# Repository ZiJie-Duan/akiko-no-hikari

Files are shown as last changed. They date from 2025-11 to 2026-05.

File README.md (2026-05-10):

# Akiko-no-Hikari (晶子の光)
# Miniature Melbourne City Lighting Model

*Read this in other languages: [简体中文](README_CH.md), [Original Chinese Version](README_CH_Original.md)*

## Project Overview
This is a farewell gift for my friend to commemorate our life in Melbourne. It's a miniature Melbourne city model with added lighting effects that can simulate sunrise, sunset, and nighttime.

**Demo Video**: https://youtu.be/LcSbfyCi86A

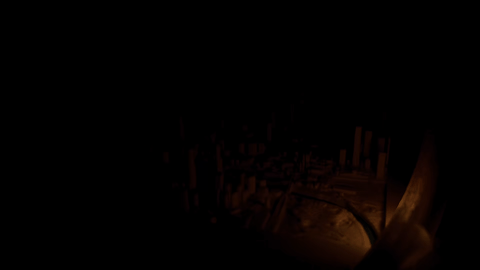
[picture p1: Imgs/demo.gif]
Project Demo


This project involves multiple steps including 3D printing, electronic soldering, and microcontroller programming. In the following text, I will explain how to build this project.

## Materials List
- **3D Printer** (I used Bambu Lab A1)
- **3D Printing Materials**:
  - PLA_Matte (for the frame)
  - PETG_Transparent (for the light-transmitting LED track)
  - Bambu Lab official materials
- **Electronic Components**:
  - Raspberry Pi Pico RP2040 (stamp pad version)
  - WS2812 LED strip (48 LEDs, high-density version with 144 LEDs/meter)
- **Tools**:
  - Electronic soldering tools (solder, soldering iron, wires, etc.)
  - Strong adhesive (for bonding PLA_Matte and PETG_Transparent materials)

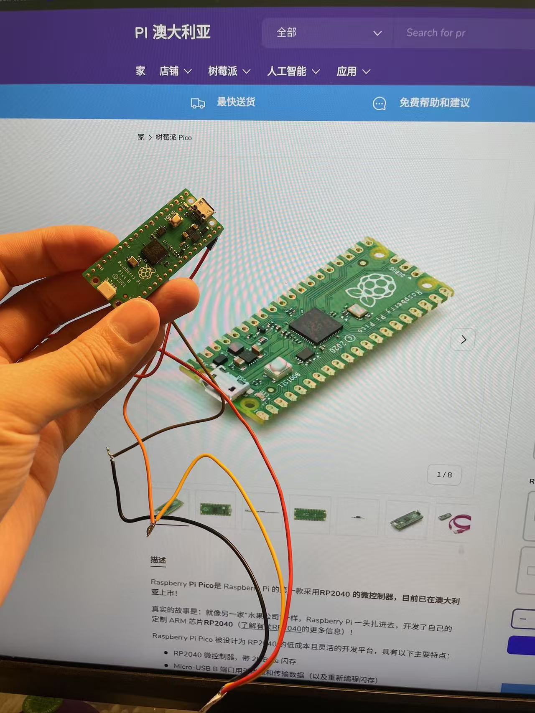
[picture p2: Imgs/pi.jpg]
Raspberry Pi Pico


## Construction Process

The construction is divided into three main steps:
1. 3D Printing
2. Assembly and Soldering
3. Programming

### 1. 3D Printing
In the `3D_models` folder of the project directory, there are three files:
- `akiko_no_hikari_project.f3d`: Complete model (can be edited with Fusion 360)
- `frame.stl`: Frame and various components (to be printed with PLA_Matte material)
- `solar_track.stl`: Light-transmitting LED track (to be printed with PETG_Transparent material)

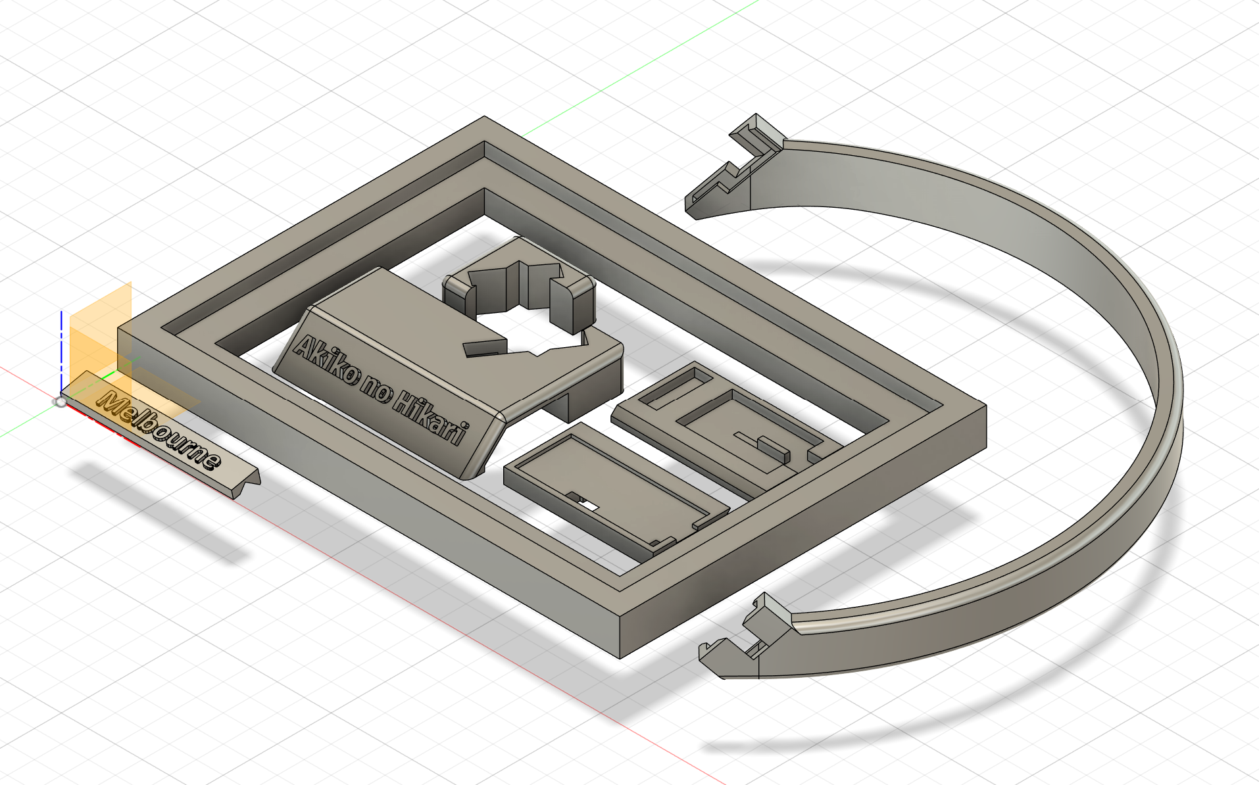
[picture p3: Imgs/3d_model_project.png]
3D Model


If you need to edit the model yourself, you can download akiko_no_hikari_project.f3d and open it with Fusion 360.

If you just want to print and assemble the model, you can directly download frame.stl and solar_track.stl for printing.

frame.stl should be printed with PLA Matte material, and solar_track.stl should be printed with PETG Transparent material.

**Printing Notes**:
- When printing `solar_track.stl`, adjust the support options:
  - Only use tree supports
  - Supports should only grow from the bottom up (no supports inside the model)
  - Pay attention to print speed and temperature control

### 2. Assembly and Soldering
1. **Connecting the Raspberry Pi Pico**:
   - Solder three wires to the stamp pads:
     - 5V power wire
     - GND ground wire
     - Data wire (Pin 22)
   - Refer to the reserved positions in the 3D printed PI bracket for the 5V and GND pad locations
   - Pay attention to the direction of the cables, as the Raspberry Pi Pico will eventually be placed in a custom bracket, so the wire direction should align with the cable slots in the bracket
   
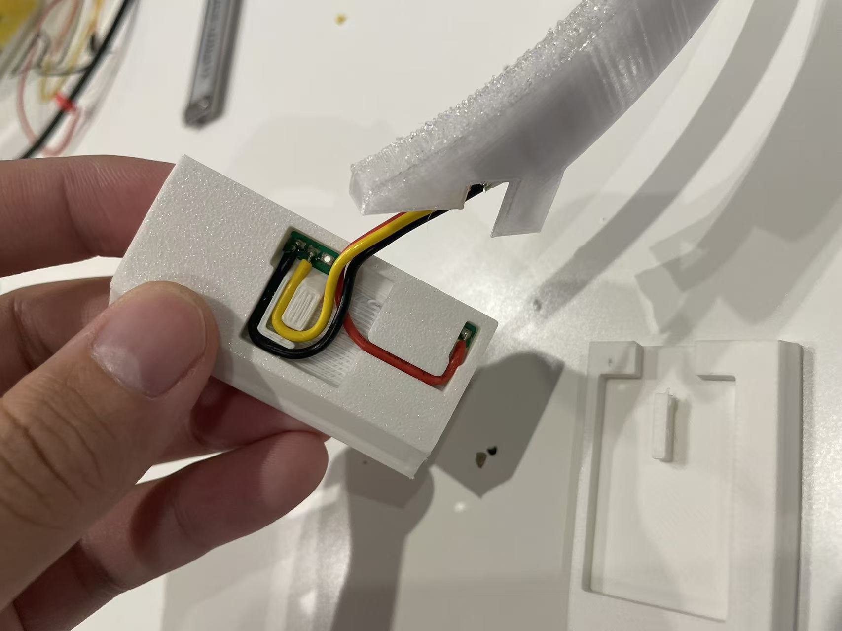
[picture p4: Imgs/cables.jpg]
Cable Connection
   

2. **LED Strip Installation**:
   - Insert the LED strip into the light track
   - Assemble the Pi bracket, right support shell, and light track, and measure the approximate positions where the three wires will reach the LED strip pads
   - Cut the wires (too short or too long will cause problems), then solder the wires to the LED strip
   - If inconvenient, you can pull out the LED strip, solder it, and then put it back into the light track. The reason we put the LED strip in first is to measure the length of the wires
   - Solder the three trimmed wires to the LED strip
   
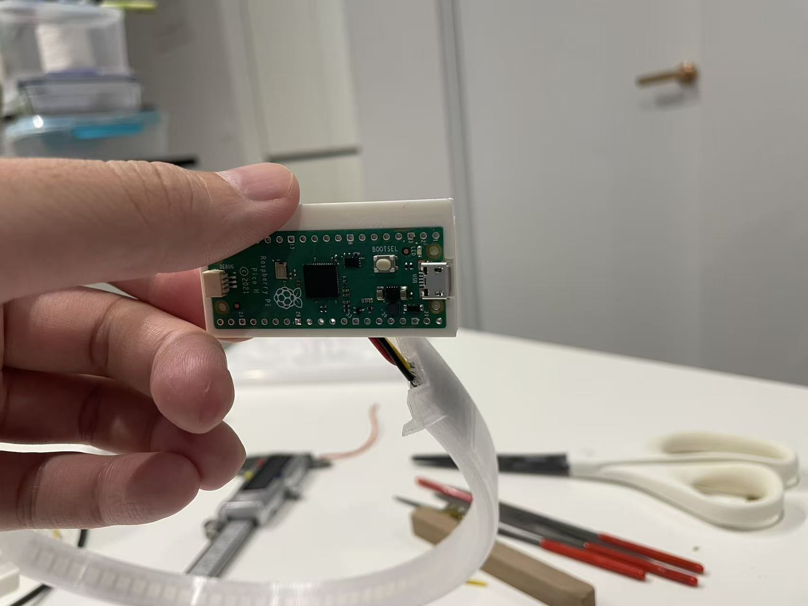
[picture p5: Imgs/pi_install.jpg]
Pi Installation
   

3. **Component Assembly**:
   - Combine the light track, left bracket, right bracket (support shell), and PI bracket, and secure them firmly with strong adhesive
   - Snap on the bottom panel of the Pi bracket (no glue needed, as this allows us to press the reset button on the development board later)

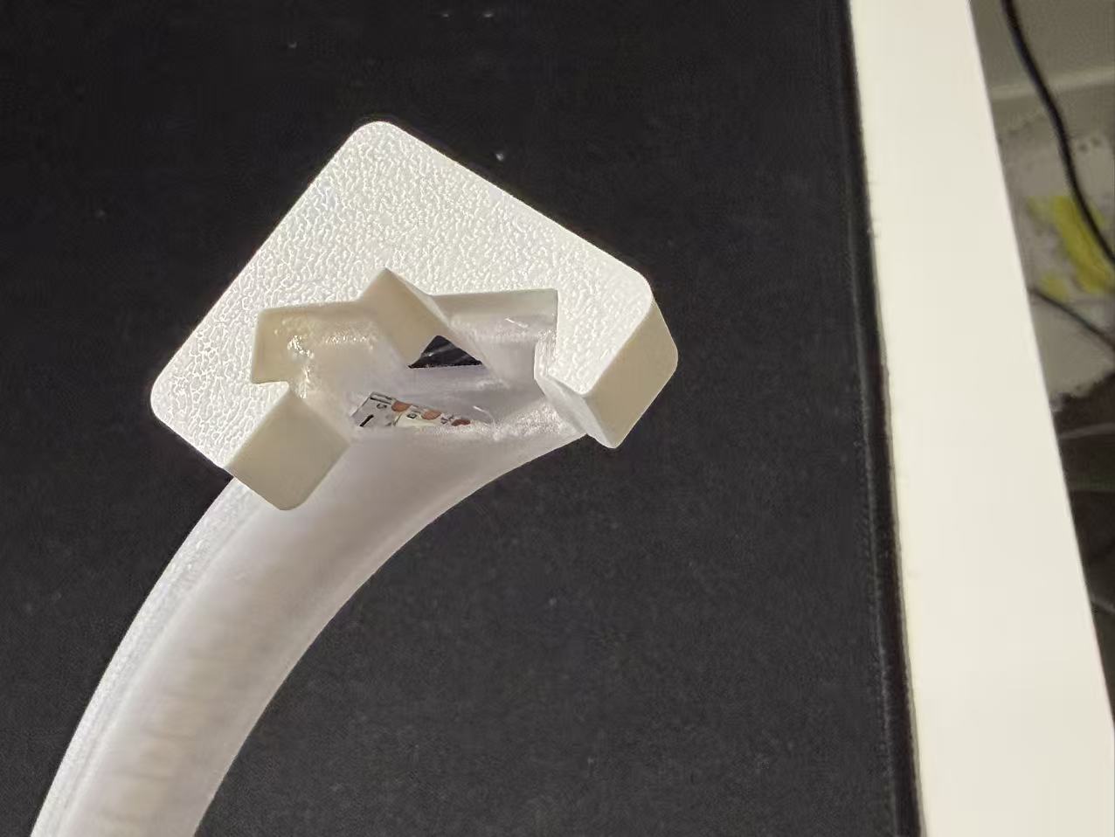
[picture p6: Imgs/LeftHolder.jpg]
Left Holder
   
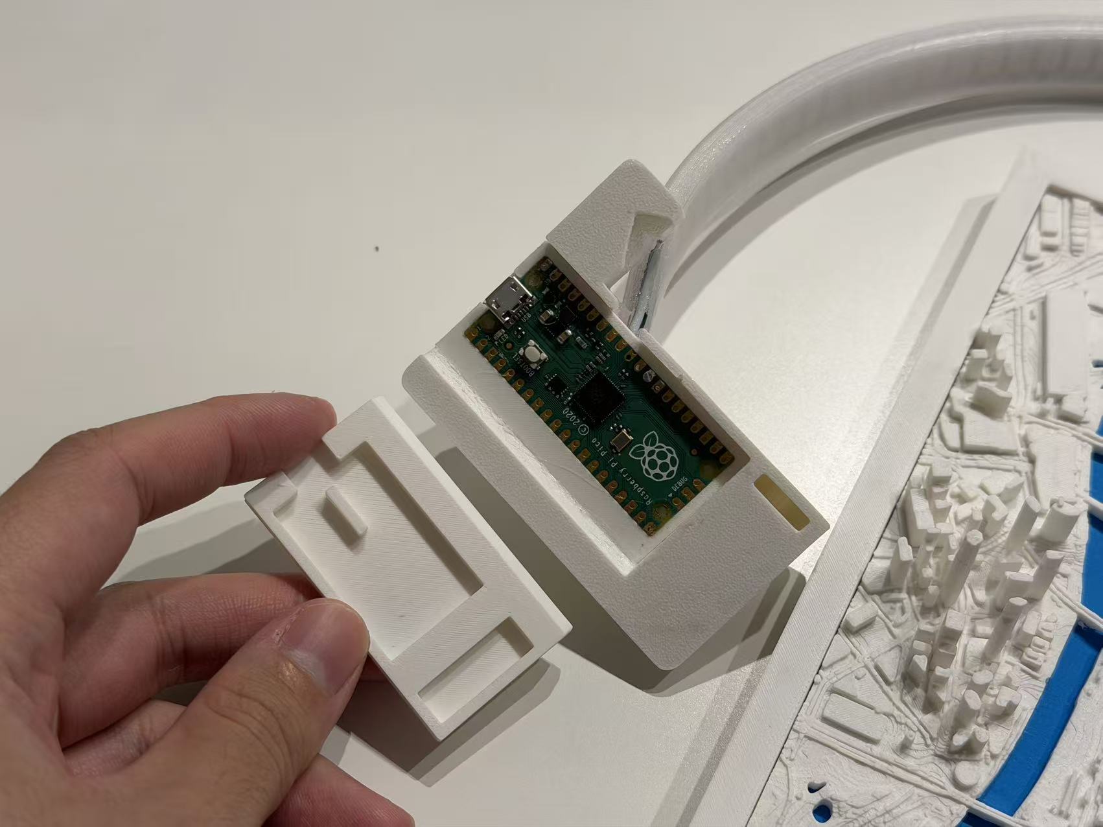
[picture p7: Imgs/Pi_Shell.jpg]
Pi Shell
   
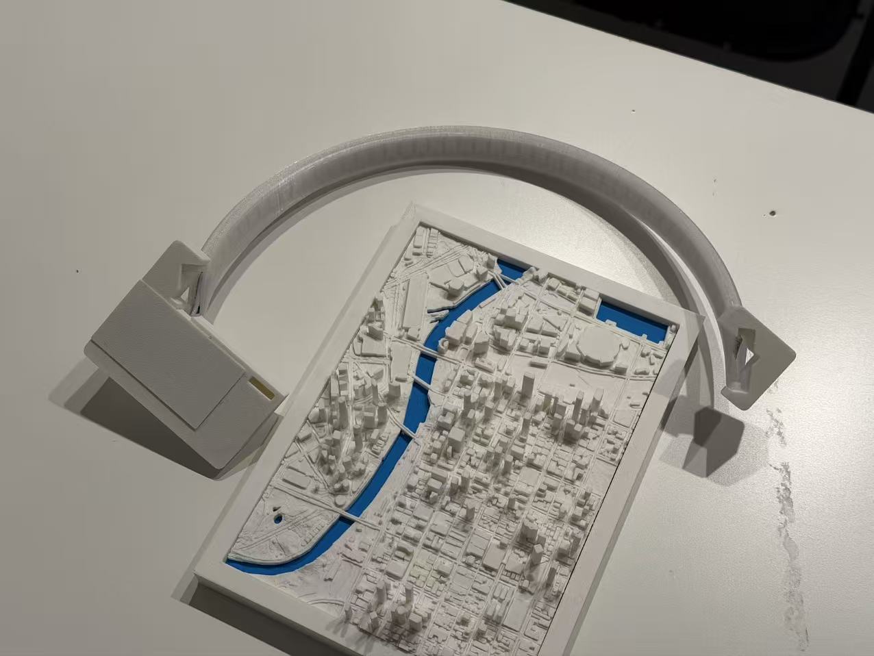
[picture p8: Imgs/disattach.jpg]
Disassembly View
   

### 3. Programming
1. Follow online steps to install MicroPython on the Pi
2. Transfer the `code/main.py` file to the Pi
3. Power on and test

## Technical Specifications
- **Controller**: Raspberry Pi Pico (RP2040)
- **LED Type**: WS2812 programmable RGB LED
- **LED Count**: 48 units
- **Data Pin**: GPIO 22
- **Communication**: PIO (Programmable Input/Output) state machine
- **Clock Frequency**: 8MHz

## Features
- Uses Gaussian functions to simulate natural light distribution
- Controls light position and diffusion range by adjusting Gaussian parameters
- Dynamically adjusts RGB color values to simulate different times of day and color temperature changes

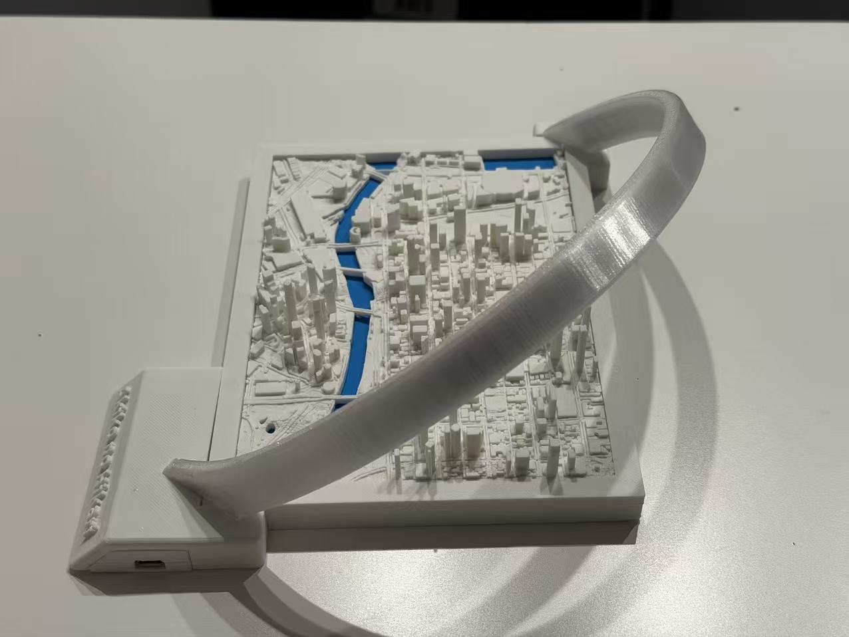
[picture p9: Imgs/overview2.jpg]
Finished Product


## Notes
The assembly and soldering parts may have some challenges. Choosing slightly thinner wires makes assembly easier.

## Contact
I hope you enjoy this model. If you have any questions, please submit an issue or contact me via email.

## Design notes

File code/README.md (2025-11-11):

# Akiko-no-Hikari (晶子の光)

## Driver Code Overview
This code represents the driver component of the Akiko-no-Hikari project. It handles the low-level LED control and light effect simulation, while the core project functionality is implemented elsewhere.

## Driver Functionality
- Controls WS2812 LED strip using PIO (Programmable Input/Output)
- Implements Gaussian light distribution algorithms
- Manages day/night cycle transitions and color temperature changes
- Provides the interface between the main project logic and physical LED hardware

## How It Works
- Uses Gaussian functions to simulate natural light distribution
- Controls light position and diffusion range by adjusting Gaussian parameters (mean μ, standard deviation σ)
- Dynamically adjusts RGB color values to simulate different times of day and color temperature changes

## Hardware Specifications
- Controller: Raspberry Pi Pico (RP2040)
- LED Type: WS2812 programmable RGB LEDs
- LED Count: 48 units
- Data Pin: GPIO 22
- Communication: PIO (Programmable Input/Output) state machine
- Clock Frequency: 8MHz

## Integration Notes
This driver code should be integrated with the main Akiko-no-Hikari project. It provides the necessary functions to control the LED hardware but requires the core project components to determine when and how lighting effects should be triggered.

## Usage
When integrated with the main project, upload the complete code to a Raspberry Pi Pico, connect the WS2812 LED strip to GPIO pin 22, and the system will respond to the main project's control signals.

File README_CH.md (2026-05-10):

# 晶子の光 (Akiko-no-Hikari)
# 墨尔本城市微缩灯光模型

## 项目概述
这是为我的朋友所做的离别礼物，为了纪念在墨尔本的生活，因此这是一个墨尔本城市微缩模型，在原有模型基础上加入了光影的效果，可以模拟日出日落和夜晚的效果。

**效果展示视频**：https://youtu.be/LcSbfyCi86A

项目演示

这个项目是一个涉及3D打印，电子焊接，单片机编程等多步骤的项目。我会在接下来的文本中介绍如何构建这个项目。

## 材料清单
- **3D打印机** (我使用的是Bambu Lab A1)
- **3D打印材料**：
  - PLA_Matte（框架部分）
  - PETG_Transparent（透光LED轨道）
  - Bambu Lab 官方材料
- **电子元件**：
  - Raspberry Pi Pico RP2040（邮票焊盘版本）
  - WS2812 LED灯带（48个，144个灯珠/米高密度版本）
- **工具**：
  - 电子焊接工具（焊锡、烙铁、线材等等）
  - 强力胶水（用于粘合PLA_Matte和PETG_Transparent材料）

Raspberry Pi Pico

## 制作流程

制作大致分为三个步骤：
1. 3D打印 
2. 组装焊接
3. 程序刷写

### 1. 3D打印
在项目文件夹下的`3D_models`文件夹中，有三个文件：
- `akiko_no_hikari_project.f3d`：整体模型（可通过Fusion 360编辑）
- `frame.stl`：框架和各种部件（使用PLA_Matte材料打印）
- `solar_track.stl`：透光LED轨道（使用PETG_Transparent材料打印）

3D模型

如果你有自行编辑模型的需求，可以直接下载akiko_no_hikari_project.f3d并通过Fusion 360打开进行编辑。

如果你只是想要打印并组装模型，可以直接下载frame.stl和solar_track.stl进行打印。

frame.stl需要使用PLA Matte材料打印，solar_track.stl需要使用PETG Transparent材料打印。

**打印注意事项**：
- 打印`solar_track.stl`时，需调整支撑选项：
  - 仅使用树状支撑
  - 支撑只允许从底部向上生长（不允许模型内部有支撑）
  - 注意控制打印速度和温度

### 2. 组装焊接
1. **连接Raspberry Pi Pico**：
   - 焊接三根线缆至邮票焊盘上，共三根线：
     - 5V电源线
     - GND地线
     - Data数据线（Pin 22）
   - 5V和GND的焊盘位置请参考上面3D模型打印出来的PI支架中预留的位置
   - 焊接时要注意线缆的方向，因为raspberry pi pico最终会被放置在一个特制的支架中，所以线引出的方向要和支架预留的线槽方向一致
   
   线缆连接

2. **LED灯带安装**：
   - 将LED灯带塞入光轨中
   - 将Pi支架和右侧支撑外壳以及光轨组装，并测量三根线到达LED灯带焊盘的大致位置
   - 剪裁电线（要是太短或者太长都会有问题），随后将电线焊接至LED灯带上
   - 如果不方便，你可以把LED灯带抽出来焊接完再塞回光轨中，为什么我们要提前把LED灯带放进去的原因是为了测量线材的长度
   - 焊接三根裁剪好的电线和LED灯带
   
   Pi安装

3. **组件组装**：
   - 将灯轨和左侧支架，右侧支架（支撑外壳），PI支架组合好并用强力胶水粘连牢固 
   - 将Pi支架的底部面板扣上去（这不需要胶水，因为后续允许我们按压开发板上的重置按钮）

   左侧支架
   Pi外壳
   拆卸图

### 3. 程序刷写
1. 按照网络上的步骤为Pi安装MicroPython
2. 将`code/main.py`文件传入Pi中
3. 上电测试

## 技术规格
- **控制器**：Raspberry Pi Pico (RP2040)
- **LED类型**：WS2812可编程RGB LED
- **LED数量**：48个
- **数据引脚**：GPIO 22
- **通信方式**：PIO (可编程输入/输出)状态机
- **时钟频率**：8MHz

## 功能特点
- 使用高斯函数模拟自然光分布
- 通过调整高斯参数控制光位置和扩散范围
- 动态调整RGB颜色值模拟不同时段和色温变化

成品展示

## 注意事项
组装焊接部分可能存在一些问题，选择稍细一点的线组装起来比较容易。

## 联系方式
希望你会喜欢这个模型。如果有任何问题，可以提交issue或发邮件来联系我。

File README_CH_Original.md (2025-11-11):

# akiko-no-hikari
Miniature Melbourne City Lighting Model

这是为我的朋友所做的离别礼物，为了纪念在墨尔本的生活，因此这是一个墨尔本城市微缩模型，在原有模型基础上加入了光影的效果，可以模拟日出日落和夜晚的效果。

以下是效果展示视频：https://youtu.be/LcSbfyCi86A

这个项目是一个涉及3D打印，电子焊接，单片机变成等 多步骤的项目。我会在接下来的文本中介绍如何构建这个项目。

材料清单：
- 3D打印机 (我使用的是Bambu Lab A1)
- 3D打印材料（PLA_Matte 和 PETG_Transparent, Bambu Lab 官方材料）
- 电子焊接工具（焊锡，烙铁，线材 等等）
- 单片机（Raspberry Pi Pico RP2040 邮票焊盘版本）
- WS2812 LED 灯带（48个， 144个灯珠/米 高密度版本）
- 强力胶水 （可以用来粘 PLA_Matte 和 PETG_Transparent）

制作大致分为三个步骤
1, 3D打印 
2, 组装焊接
3, 程序刷写

# 3D打印
在项目文件夹 下的 3D_models 文件夹中，有三个文件：
- akiko_no_hikari_project.f3d （整体模型）
- frame.stl (PLA_Matte 材料打印的框架 和 各种部件)
- solar_track.stl (PETG_Transparent 材料打印的透光LED轨道)

如果你有自行编辑模型的需求，可以直接下载akiko_no_hikari_project.f3d并通过Fusion 360 打开进行编辑。

如果你只是想要打印并组装模型，可以直接下载frame.stl和solar_track.stl进行打印。

frame.stl 需要使用 PLA Matte 材料打印，solar_track.stl 需要使用 PETG Transparent 材料打印。

注意，在打印 solar_track.stl 时，需要调整支撑选项，只允许使用树状支撑，并且支撑只允许从底部向上生长（不允许模型内部有支撑）。然后注意打印速度和温度控制。

# 组装焊接
1, 将线缆焊接至 raspberry pi pico 的邮票焊盘上，共三根线
- 5V 电源线 
- GND 地线
- Data 数据线 Pin 22
5V和GND的焊盘位置请参考上面3D模型打印出来的 PI 支架中预留的位置。
焊接时要注意线缆的方向，因为 raspberry pi pico 最终会被放置在一个特制的支架中，所以线引出的方向要和支架预留的线槽方向一致。
（Pi 在支架中，并且线缆已经连接完成 /home/zijie/akiko-no-hikari/Imgs/cables.jpg）
2, 将led灯带塞入光轨中
3, 将Pi支架和右侧支撑外壳 以及 光轨组装，并测量三根线到达LED灯带焊盘的大致位置
4, 剪裁电线（要是太短或者太长都会有问题），随后将电线焊接至LED灯带上。（如果不方便，你可以把LED灯带抽出来 焊接完再塞回光轨中，为什么 我们要提前把LED灯带放进去的原因是为了测量线材的长度）
5, 焊接三根裁剪好的电线和LED灯带。
6, 将灯轨 和 左侧支架 ，右侧支架（支撑外壳），PI支架 组合好并用强力胶水粘连牢固 
7, 将Pi支架的底部面板扣上去（这不需要胶水，因为后续允许我们按压开发板上的重置按钮）

# 程序刷写
1, 按照网络上的步骤为Pi 安装 Micropython
2, 将/home/zijie/akiko-no-hikari/code/main.py 文件传入Pi中
3，上电测试

以上就是整个模型组装的所有步骤，这个模型的 组装焊接部分可能存在一些问题，选择稍细一点的线组装起来比较容易。

希望你会喜欢这个模型。如果有任何问题，可以提交issue或发邮件来联系我。

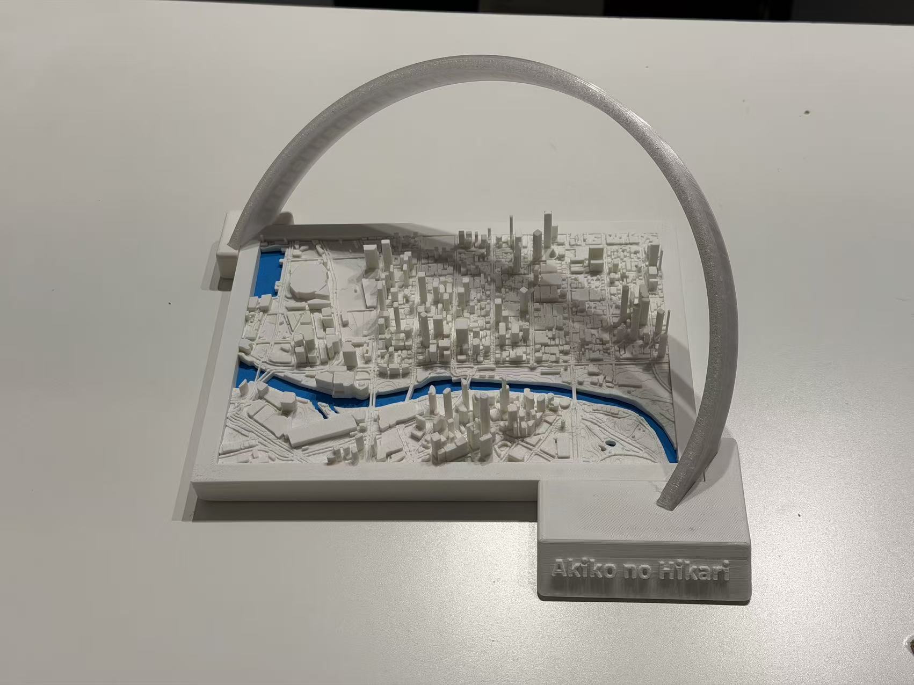
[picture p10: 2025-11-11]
Imgs/overview.jpg

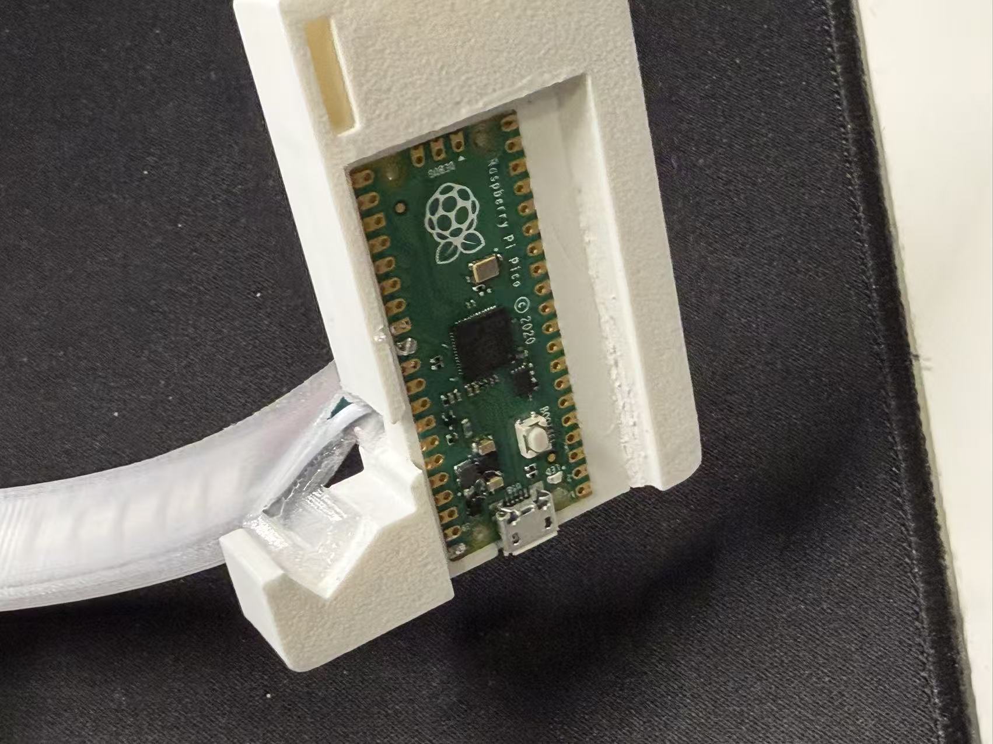
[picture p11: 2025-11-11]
Imgs/RightHolder.jpg

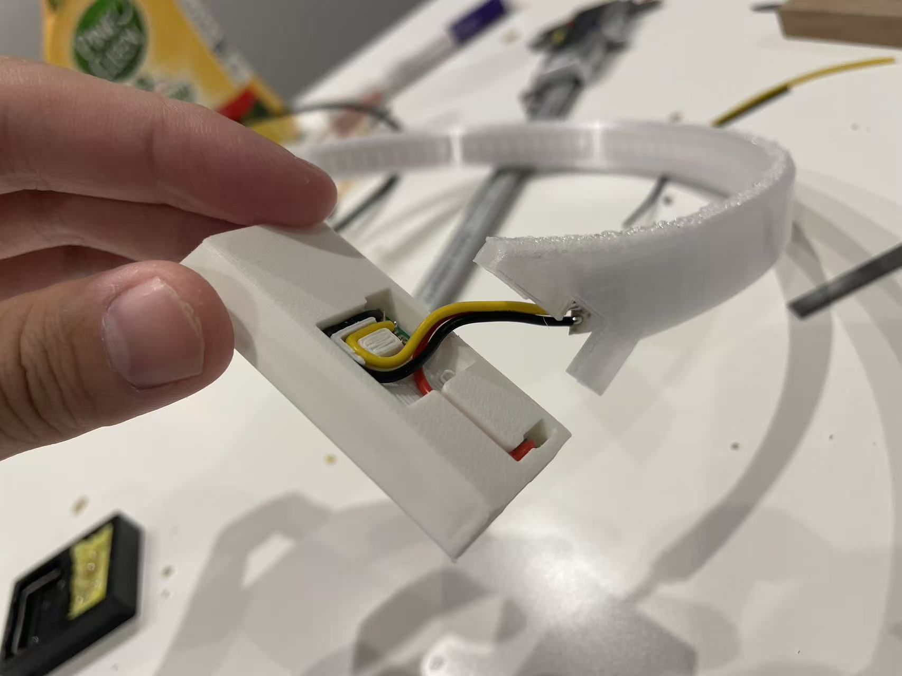
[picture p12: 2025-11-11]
Imgs/more_connection.jpg

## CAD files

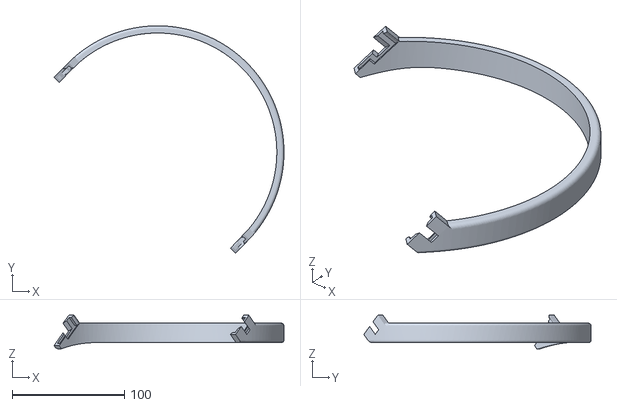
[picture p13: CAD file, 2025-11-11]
3D_models/solar_track.stl
204.6 x 202.3 x 29.9

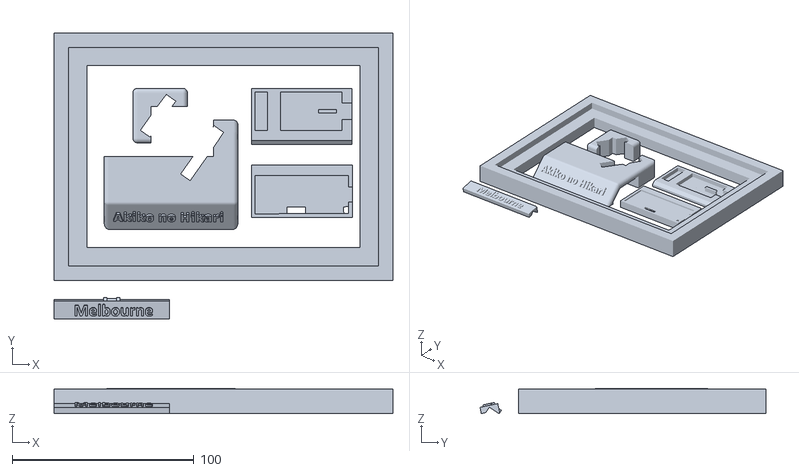
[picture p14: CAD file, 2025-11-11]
3D_models/frame.stl
186.3 x 157.2 x 14.0

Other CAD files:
3D_models/akiko-no-hikari-project.f3d

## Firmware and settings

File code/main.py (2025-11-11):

# Example using PIO to drive a set of WS2812 LEDs.

import array, time
from machine import Pin
import rp2
import math

# Configure the number of WS2812 LEDs.
NUM_LEDS = 48
PIN_NUM = 22
brightness = 0.2

@rp2.asm_pio(sideset_init=rp2.PIO.OUT_LOW, out_shiftdir=rp2.PIO.SHIFT_LEFT, autopull=True, pull_thresh=24)
def ws2812():
    T1 = 2
    T2 = 5
    T3 = 3
    wrap_target()
    label("bitloop")
    out(x, 1)               .side(0)    [T3 - 1]
    jmp(not_x, "do_zero")   .side(1)    [T1 - 1]
    jmp("bitloop")          .side(1)    [T2 - 1]
    label("do_zero")
    nop()                   .side(0)    [T2 - 1]
    wrap()


# Create the StateMachine with the ws2812 program, outputting on pin
sm = rp2.StateMachine(0, ws2812, freq=8_000_000, sideset_base=Pin(PIN_NUM))

# Start the StateMachine, it will wait for data on its FIFO.
sm.active(1)

# Display a pattern on the LEDs via an array of LED RGB values.
# ar = array.array("I", [0 for _ in range(NUM_LEDS)])

##########################################################################

def gaussian(x, mu=0, sigma=1):
    """
    One-dimensional Gaussian function implementation for MicroPython.
    
    Parameters:
    - x: independent variable
    - mu: mean (μ), default 0
    - sigma: standard deviation (σ), default 1
    
    Returns:
    - Value of the Gaussian function at x
    """
    coeff = 1 / (sigma * math.sqrt(2 * math.pi))
    exponent = -((x - mu) ** 2) / (2 * sigma ** 2)
    return coeff * math.exp(exponent)

def gaussian_peak_1(x, mu=0, width=1):
    """
    Generate a Gaussian curve with peak value of 1, with adjustable width.
    
    Parameters:
    - x: input value
    - mu: peak position
    - width: controls curve width (larger values make it more gradual)
    
    Returns:
    - Curve value, with maximum of 1
    """
    return math.exp(-((x - mu) / width) ** 2)

class LEDD:
    
    def __init__(self, led_num = NUM_LEDS):
        self.led_num = led_num
        self.ar = array.array("I", [0 for _ in range(NUM_LEDS)])
    
    def pset(self, i, color):
        self.ar[i] = (color[1]<<16) + (color[0]<<8) + color[2]

    def show(self):
        dimmer_ar = array.array("I", [0 for _ in range(NUM_LEDS)])
        for i,c in enumerate(self.ar):
            r = int(((c >> 8) & 0xFF) * brightness)
            g = int(((c >> 16) & 0xFF) * brightness)
            b = int((c & 0xFF) * brightness)
            dimmer_ar[i] = (g<<16) + (r<<8) + b
        sm.put(dimmer_ar, 8)
    
    def fill(self, color):
        for i in range(self.led_num):
            self.pset(i, color)
    
    def set_ar(self, ar):
        self.ar = ar


            
class Sun:
    
    def __init__(self, led):
        self.sigma = 2
        self.mu = 0
        self.speed = 0
        self.led = led
        self.color_set = (0,0,0)
        
    def _to_color(self, i):
        r = self.color_set[0] * i
        g = self.color_set[1] * i
        b = self.color_set[2] * i
        return int(r), int(g), int(b)
        #return (max(int(r),25), max(int(g),22), max(int(b),15))
    
    def _set_color(self,r,g,b):
        self.color_set=(r,g,b)
    
    def _get_sample(self):
        self.led.fill((0,0,0))
        for i in range(48):
            self.led.pset(i, self._to_color(gaussian_peak_1(i, self.mu - 4, self.sigma)))
    
    def _speed_change(self):
        #self. mu max 58
        abs_mu = max(0, self.mu)
        #print(abs_mu, 0.06 + 0.0035 * (26 - abs(22-abs_mu)))
        self.speed = 0.05 + 0.0015 * (26 - abs(22-abs_mu))
        
    def _day_sigma_change(self):
        #self. mu max 58
        abs_mu = max(0, self.mu)
        #print(abs_mu, 0.06 + 0.0035 * (26 - abs(22-abs_mu)))
        self.sigma = 2 + 0.15 * (26 - abs(25-abs_mu))
        #print(self.sigma)
    
    def _day_color_change(self):
        #self. mu max 58
        abs_mu = max(0, self.mu)
        #print(abs_mu, 0.06 + 0.0035 * (26 - abs(22-abs_mu)))
        r = self.color_set[0]
        g = self.color_set[1] - 6.5 * abs(25-abs_mu) 
        b = max(0,self.color_set[2] - 8 * abs(25-abs_mu))
        self._set_color(r,g,b)
        
    def _day_time(self):
        self.sigma = 2
        self.mu = 0
        self._set_color(255, 220, 150)
        for _ in range(800):
            self._set_color(255, 220, 150)
            self._day_color_change()
            print(self.mu)
            #print(self.color_set)
            self._day_sigma_change()
            self._speed_change()
            self.mu += self.speed
            self._get_sample()
            led.show()
            
    
    def _night_time(self):
        self.sigma = 2
        self.mu = 0.2
        self._set_color(60, 70, 150)
        self.speed = 0.1
        for _ in range(550):
            self.mu += self.speed - 0.003 * max(0, (10 - self.mu))
            self._get_sample()
            led.show()
            
                
    def run(self):
        while True:
            self._day_time()
            self._night_time()
            

print("st")
led = LEDD()
s = Sun(led)
time.sleep(5)
s.run()
print("end")

#[50, 10 , 0] sunrise
#[100, 50, 10] morning
#[250, 150, 130] noon
#

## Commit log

2025-11-11 docs: update document
    [akiko-no-hikari-project.f3d, frame.stl, solar_track.stl]
2026-05-10 feat: add demo GIF and Melbourne city model
    - Insert demo GIF into README (EN/ZH) for better first impression
    - Add Melbourne.stl 3D model supplement
